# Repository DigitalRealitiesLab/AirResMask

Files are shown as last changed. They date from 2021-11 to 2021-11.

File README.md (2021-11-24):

# AirResMask

The repository contains building plans for the AirRes mask described in the following publication. Please cite this publication, if you build upon content of this repository:

Markus Tatzgern, Michael Domhardt, Martin Wolf, Michael Cenger, Gerlinde Emsenhuber, Radomir Dinic, Nathalie Gerner, and Arnulf Hartl. 2022. AirRes Mask: A Precise and Robust Virtual Reality Breathing Interface Utilizing Breathing Resistance as Output Modality. In CHI Conference on Human Factors in Computing Systems (CHI ’22), April 29-May 5, 2022, New Orleans, LA, USA. ACM, New York, NY, USA, https://doi.org/10.1145/3491102.3502090

The assembled mask:

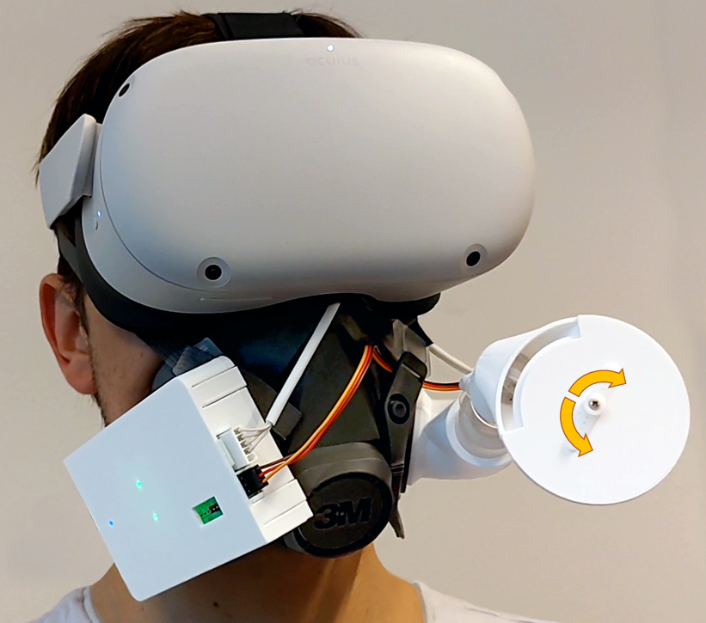
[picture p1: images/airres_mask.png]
Assembled Mask


Exploded view of mask showing components:

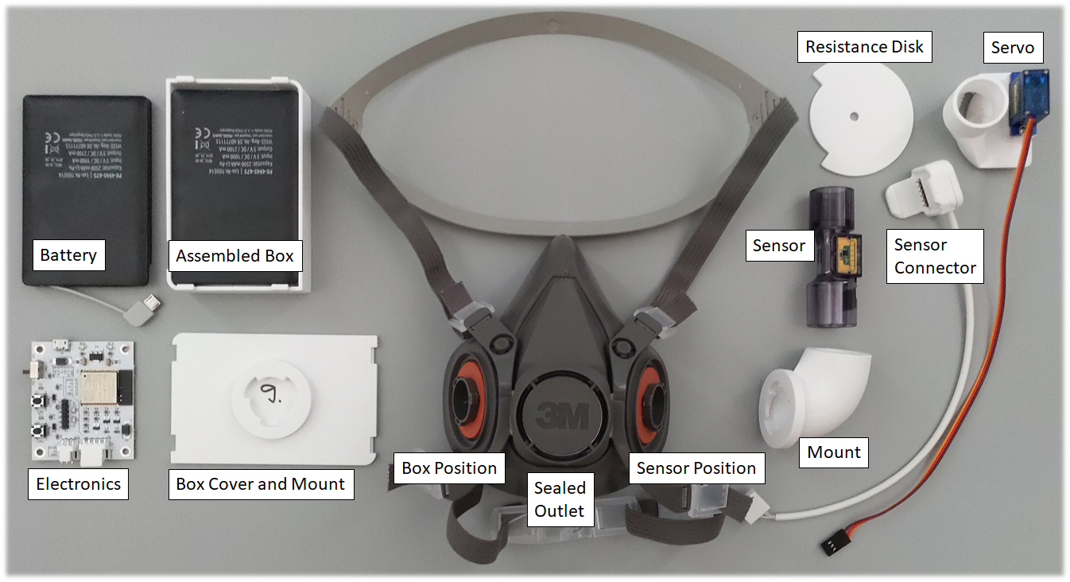
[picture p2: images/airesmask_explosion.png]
Exploded view of mask


Example applications realized with mask:

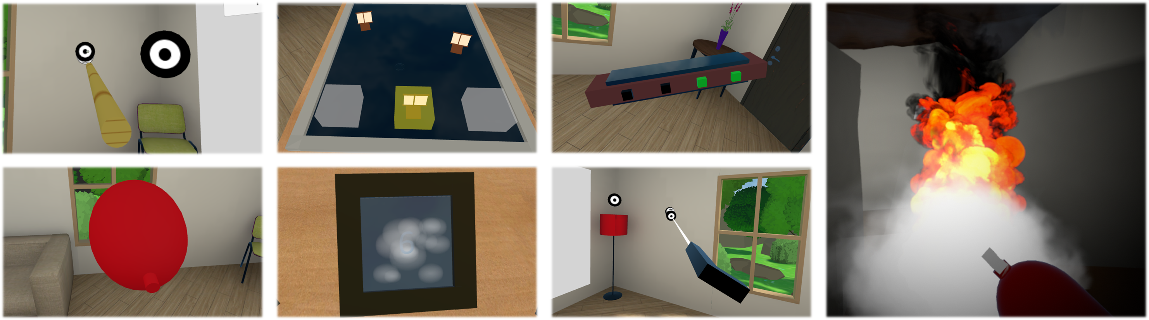
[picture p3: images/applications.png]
Example applications


This repository contains in the following folders:
- CAD: 3D models and printer files for custom parts of the mask
- Electronics: plans for custom electronics including a Bluetooth module
- Software: control software for the electronics and a Unity sample

Additional part list:
- Sensirion Mass Flow Meter [SFM3300](https://www.sensirion.com/en/flow-sensors/mass-flow-meters-for-high-precise-measurement-of-gases/proximal-flow-sensors-sfm3300-autoclavable-washable-or-single-use/) 
- [3M Respirator 6300](https://www.3m.com/3M/en_US/p/d/v000057396/)
- Servomotor SG90
- Power Bank with Micro USB connector

3rd party CAD files that could be interesting:
- [Servomotor SG90](https://grabcad.com/library/sg90-micro-servo-9g-tower-pro-1)
- Sensors: [SFM3300-D](https://www.sensirion.com/fileadmin/user_upload/customers/sensirion/Dokumente/5_Mass_Flow_Meters/Software/Sensirion_Mass_Flow_Meters_Software_SFM3300-D.step), [SFM3300-AW](https://www.sensirion.com/fileadmin/user_upload/customers/sensirion/Dokumente/5_Mass_Flow_Meters/Software/Sensirion_Mass_Flow_Meters_Software_SFM3300-D.step)

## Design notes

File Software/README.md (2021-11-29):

# Software

## Electronics

We use the [ESP32 library](https://github.com/espressif/arduino-esp32) of Espressif for programming the board.
In the folder ''Electronics'' you can find a file to program the circuit board, as well as the [ESP32Servo](https://github.com/madhephaestus/ESP32Servo) library. To upload the software to the board you need a SH-U09C2 or similar USB adapter.

You can find more ways to read and process SFML3300 sensor data [here](https://github.com/MyElectrons/sfm3300-arduino).

## UnitySample

This folder contains a simple Unity sample that demonstrates a version of the breathing engine where sensor values are received, transformed to forces to apply to the scene and breathing resistance can be set. To reduce the file size, we removed dependencies to the Oculus SDK. 

Additional 3rd party assets can be retrieved from the Unity Asset store:
[Arduino Bluetooth Plugin](https://assetstore.unity.com/packages/tools/input-management/arduino-bluetooth-plugin-98960)

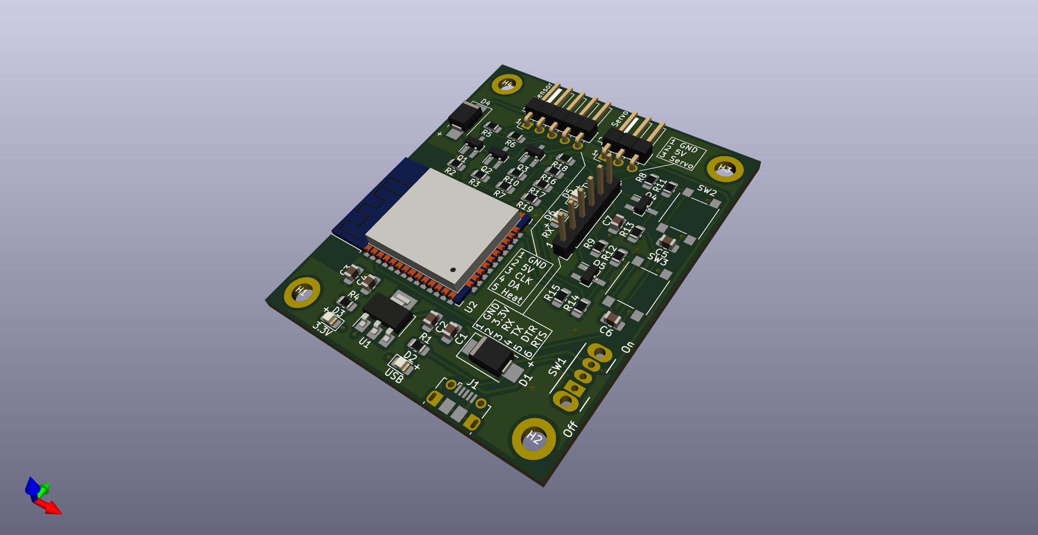
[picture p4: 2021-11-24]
Electronics/KiCAD/RespiratorIF_Board_3D_Front.jpg

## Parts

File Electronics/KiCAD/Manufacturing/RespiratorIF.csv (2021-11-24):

Comment | Designator | Footprint | LCSC
100nF | C1,C3 | Capacitor_SMD:C_0805_2012Metric_Pad1.18x1.45mm_HandSolder | C282732
47µF/10V | C2,C4 | Capacitor_SMD:C_1206_3216Metric_Pad1.33x1.80mm_HandSolder | C607993
1µF | C5,C6 | Capacitor_SMD:C_0805_2012Metric_Pad1.18x1.45mm_HandSolder | C46653
SK24 | D1,D4 | Diode_SMD:D_SMB_Handsoldering | C85272
LED green | D2,D3 | LED_SMD:LED_0805_2012Metric_Pad1.15x1.40mm_HandSolder | C84260
LED yellow | D5,D6 | LED_SMD:LED_0805_2012Metric_Pad1.15x1.40mm_HandSolder | C2296
MountingHole | H1,H2,H3,H4 | MountingHole:MountingHole_3.2mm_M3_ISO14580_Pad
Power | J1 | Connector_USB:USB_Micro-B_Molex-105017-0001 | C136000
Servo | J2 | Connector_PinHeader_2.54mm:PinHeader_1x03_P2.54mm_Horizontal | C92159
Sensor | J3 | Connector_PinHeader_2.54mm:PinHeader_1x05_P2.54mm_Horizontal | C492413
Program | J4 | Connector_PinHeader_2.54mm:PinHeader_1x06_P2.54mm_Vertical | C492405
BSS138 | Q1,Q2 | Package_TO_SOT_SMD:SOT-23_Handsoldering | C78284
AO3400A | Q3 | Package_TO_SOT_SMD:SOT-23_Handsoldering | C347475
S8050 | Q4,Q5 | Package_TO_SOT_SMD:SOT-23_Handsoldering | C444723
4.7kΩ | R1 | Resistor_SMD:R_0805_2012Metric_Pad1.20x1.40mm_HandSolder | C17673
100Ω | R11 | Resistor_SMD:R_0805_2012Metric_Pad1.20x1.40mm_HandSolder | C17408
470Ω | R14,R15 | Resistor_SMD:R_0805_2012Metric_Pad1.20x1.40mm_HandSolder | C21266
1kΩ | R4,R16,R17 | Resistor_SMD:R_0805_2012Metric_Pad1.20x1.40mm_HandSolder | C17513
10kΩ | R2,R3,R6,R7,R8,R9,R10,R12,R13 | Resistor_SMD:R_0805_2012Metric_Pad1.20x1.40mm_HandSolder | C17414
20kΩ | R5 | Resistor_SMD:R_0805_2012Metric_Pad1.20x1.40mm_HandSolder | C4328
Off/On | SW1 | Button_Switch_THT:SW_CuK_OS102011MA1QN1_SPDT_Angled | C393937
Reset | SW2 | Button_Switch_SMD:SW_Push_1P1T_NO_6x6mm_H9.5mm | C127509
Boot | SW3 | Button_Switch_SMD:SW_Push_1P1T_NO_6x6mm_H9.5mm | C127509
AMS1117-3.3 | U1 | Package_TO_SOT_SMD:SOT-223-3_TabPin2 | C6186
ESP32-WROOM-32 | U2 | RF_Module:ESP32-WROOM-32 | C82899

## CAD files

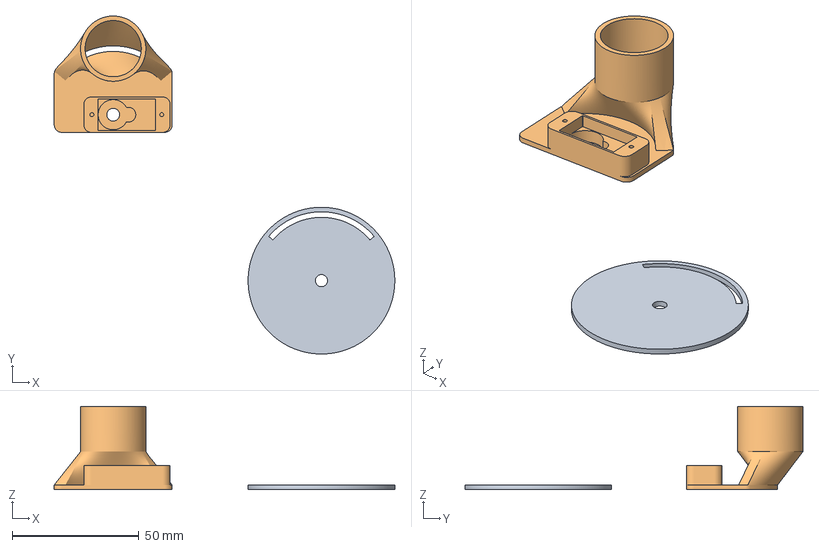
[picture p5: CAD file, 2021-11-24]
CAD/3D Print/AirValve_v3.3mf
134.6 x 133.5 x 32.8 mm
a3ac0385-cfff-4e33-9931-d9343202ccc4.stl
a6713ac3-0c4d-4182-9d5a-94dde946e7b5.stl

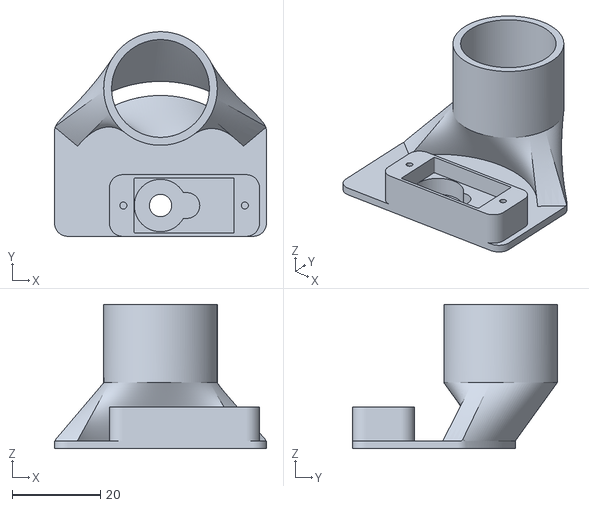
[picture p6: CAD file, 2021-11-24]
CAD/3D Print/gapWidth variable/Air Duct 3.1828.stl
48.2 x 46.5 x 32.8

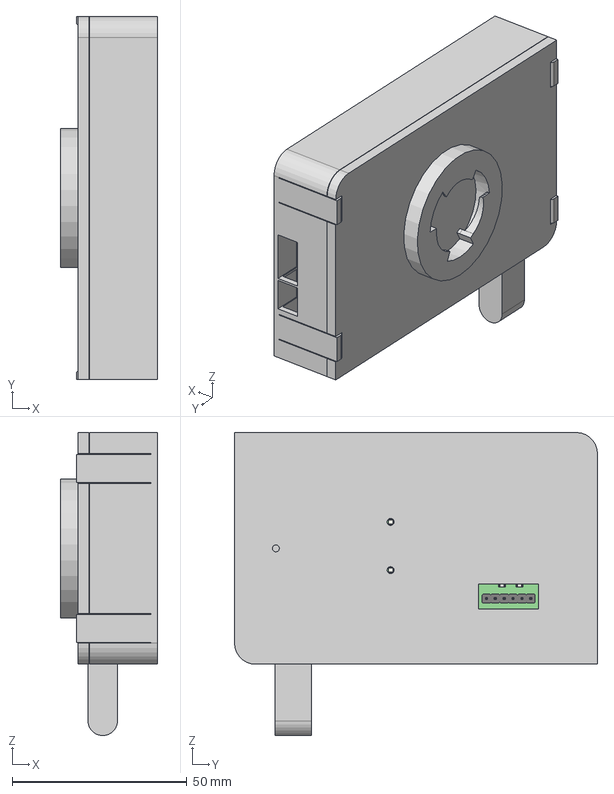
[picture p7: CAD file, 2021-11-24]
CAD/3M 6000 Series Electronic Box/3M 6000 Series Electronic Box v30.step
27.7 x 104.0 x 86.8 mm
Power Bank
Electronic Box

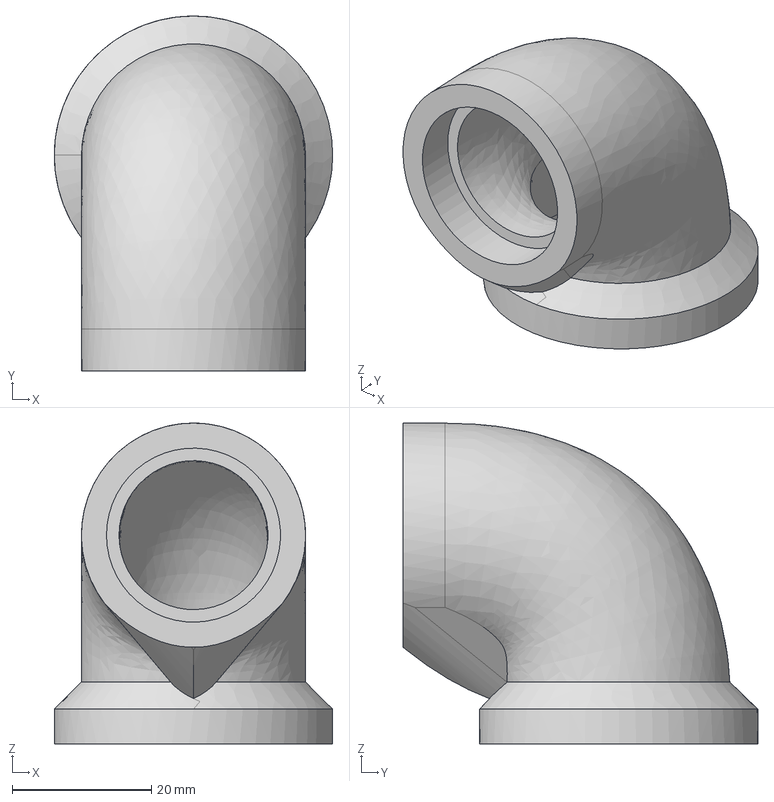
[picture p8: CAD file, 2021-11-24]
CAD/3M 6000 Series Sensor Adapter/3M 6000 Series Connector v3 v10.step
40.0 x 51.0 x 46.1 mm

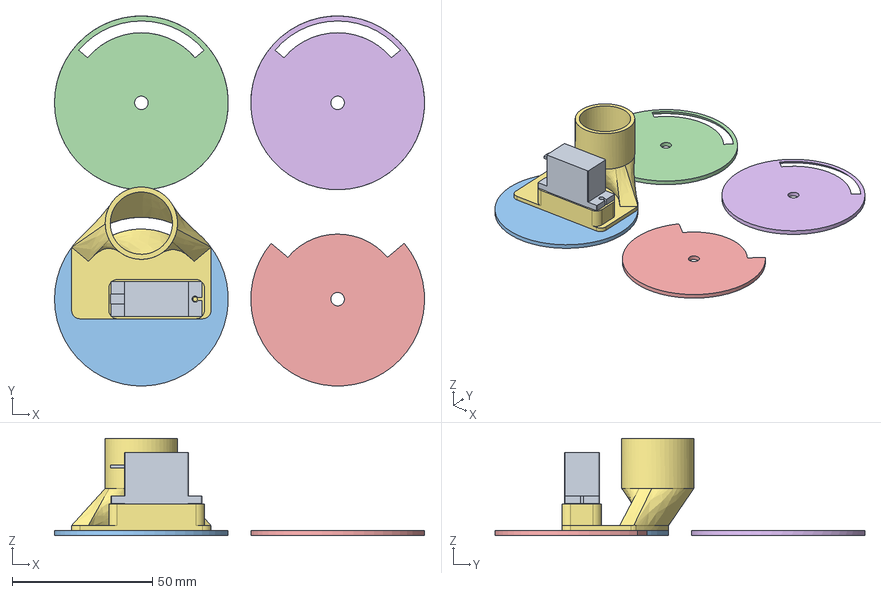
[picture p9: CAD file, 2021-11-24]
CAD/AirRestrictor/Air Valve 3rd Prototype v20.step
132.0 x 131.9 x 34.6 mm
servo
splined-drive
Air Restrictor
Air Duct

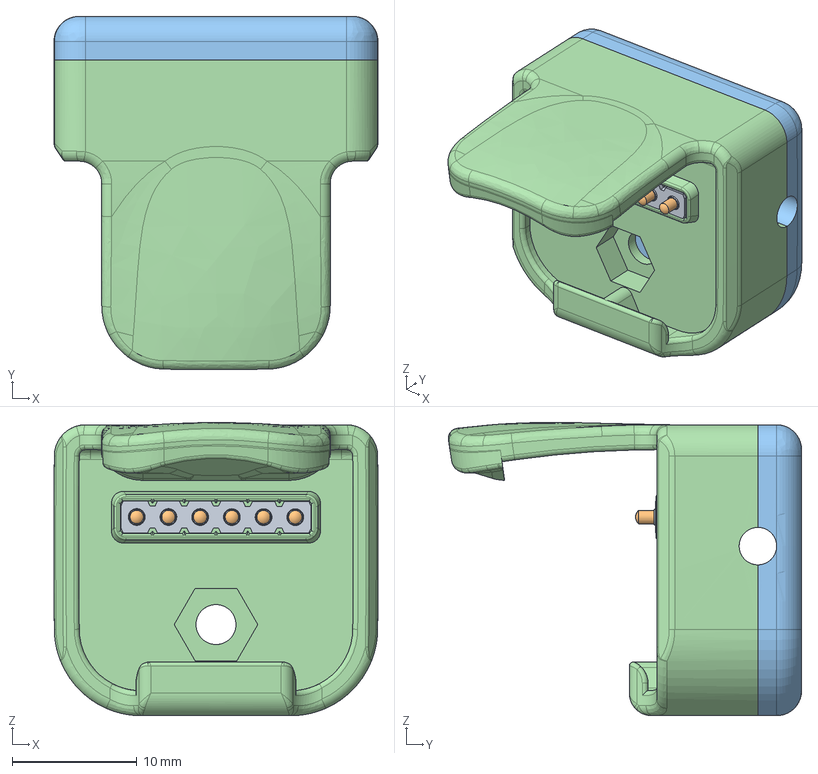
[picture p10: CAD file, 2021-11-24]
CAD/SensorPlug/SensorCap v2.step
25.9 x 28.3 x 23.5 mm

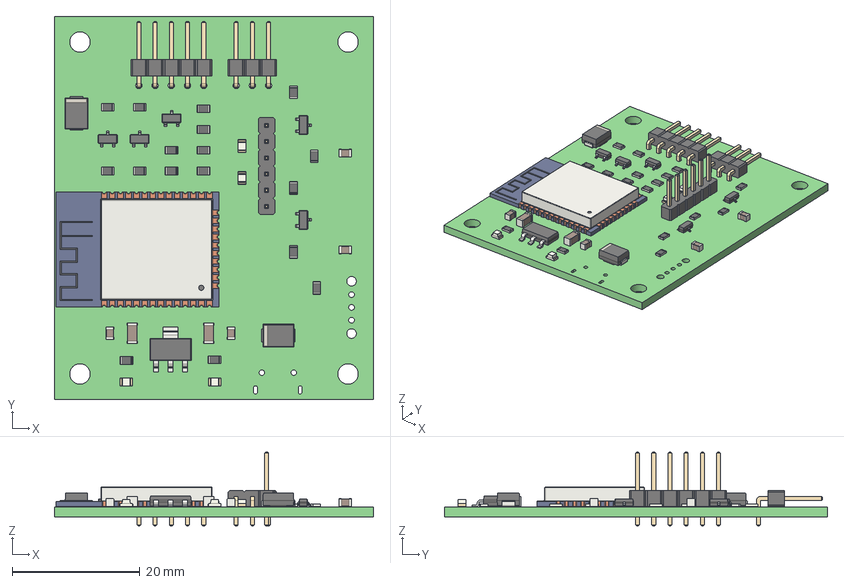
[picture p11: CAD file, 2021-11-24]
Electronics/Export4CAD/RespiratorIF v1.step
50.0 x 60.0 x 11.5 mm

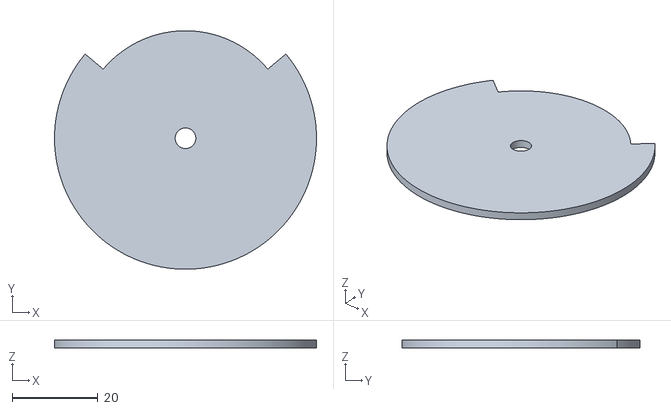
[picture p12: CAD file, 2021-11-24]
CAD/3D Print/gapWidth variable/Air Restrictor Clearance 3.6828.stl
61.0 x 55.5 x 1.80

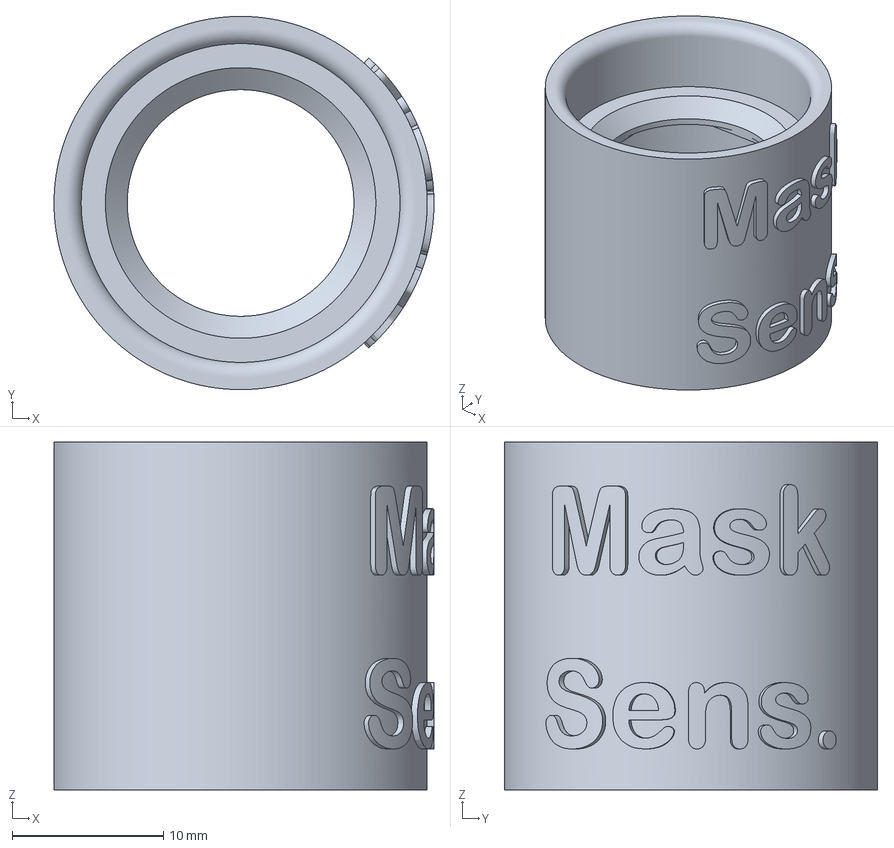
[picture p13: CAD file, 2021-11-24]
CAD/3D Print/Mask-Sensor-Adapter.3mf
25.2 x 24.7 x 23.0 mm

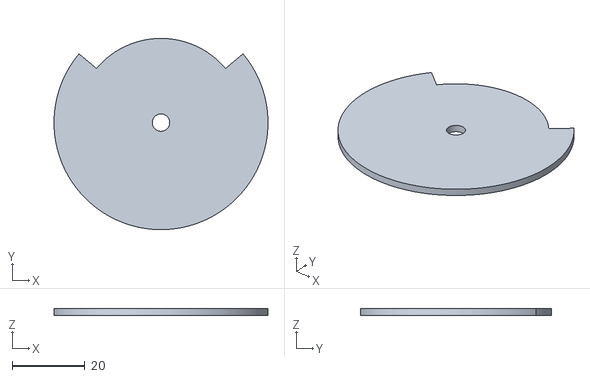
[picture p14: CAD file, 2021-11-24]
CAD/3D Print/gapWidth variable/Air Restrictor Clearance 2.6828.stl
59.0 x 52.7 x 1.80

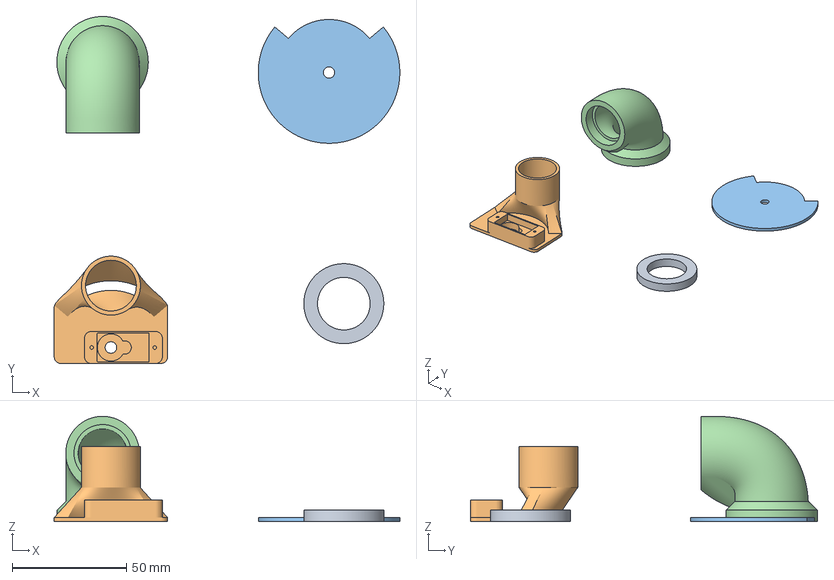
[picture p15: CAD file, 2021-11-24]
CAD/3D Print/MaskParts.3mf
151.3 x 151.9 x 46.1 mm
Ring.stl
Duct.stl
Disk.stl
Elbow.stl

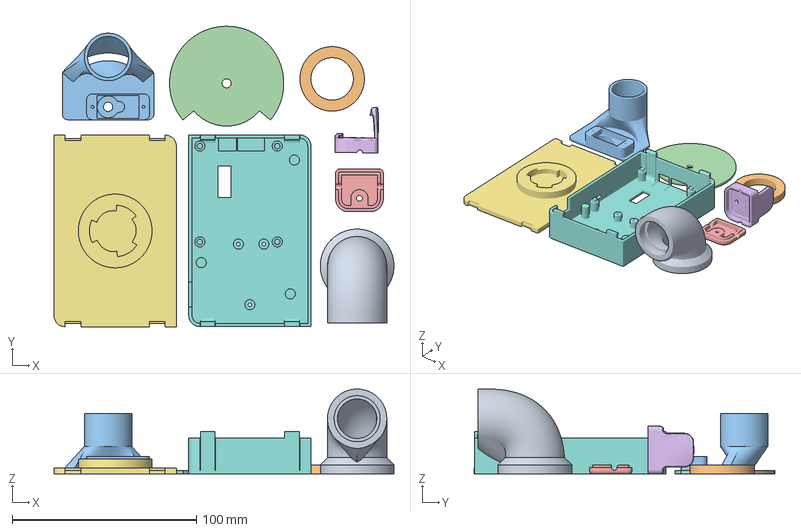
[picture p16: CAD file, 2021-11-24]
CAD/3D Print/AllParts4OneParticipant.3mf
184.5 x 163.1 x 46.1 mm
AirElbow.stl
AirBlockingRing.stl
AirDuct.stl
AirRestrictorDisc.stl
SensorClipLid.stl
SensorClip.stl
ElectronicBoxMedialHalf.stl
ElectronicBoxLateralHalf.stl

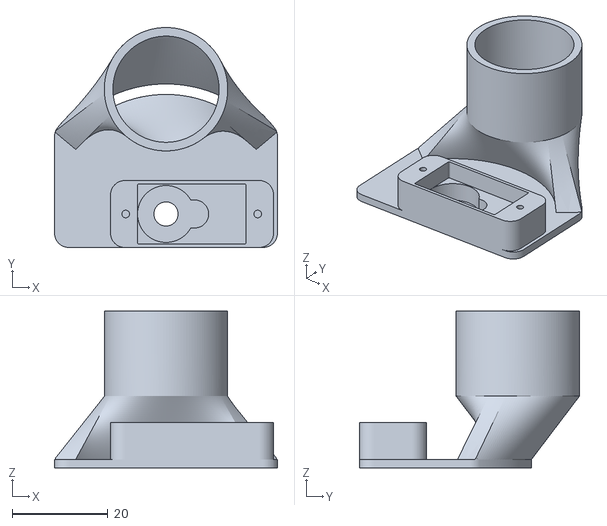
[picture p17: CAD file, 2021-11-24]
CAD/3D Print/gapWidth variable/Air Duct 2.1828.stl
46.6 x 46.0 x 32.8

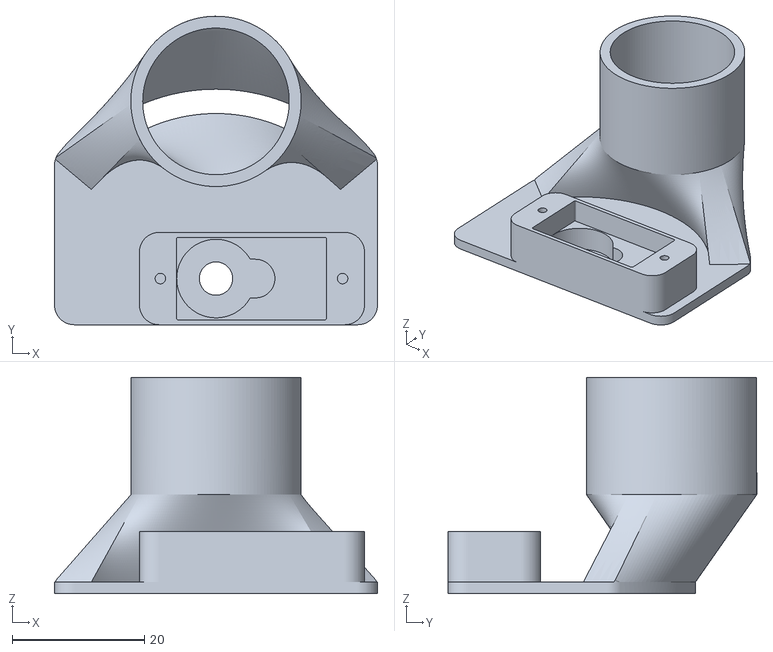
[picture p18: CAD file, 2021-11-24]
CAD/3D Print/gapWidth variable/Air Duct 3.6828.stl
48.9 x 46.7 x 32.8

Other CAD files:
CAD/3D Print/Plug Cover.stl
CAD/3D Print/gapWidth variable/Air Duct 2.6828.stl
CAD/3D Print/Plug Body.stl
CAD/3D Print/gapWidth variable/Air Restrictor Clearance 4.1828.stl
CAD/3D Print/Plug.3mf
CAD/3D Print/gapWidth variable/Air Duct 4.1828.stl
CAD/3D Print/gapWidth variable/Air Restrictor Clearance 2.1828.stl
CAD/3D Print/gapWidth variable/Air Restrictor Clearance 3.1828.stl
CAD/3M 6000 Series Electronic Box/3M 6000 Series Electronic Box v30.f3z
CAD/3M 6000 Series Sensor Adapter/3M 6000 Series Connector v3 v10.f3z
CAD/AirRestrictor/Air Valve 3rd Prototype v20.f3z
CAD/SensorPlug/SensorCap v2.f3d
Electronics/Export4CAD/RespiratorIF v1.f3d

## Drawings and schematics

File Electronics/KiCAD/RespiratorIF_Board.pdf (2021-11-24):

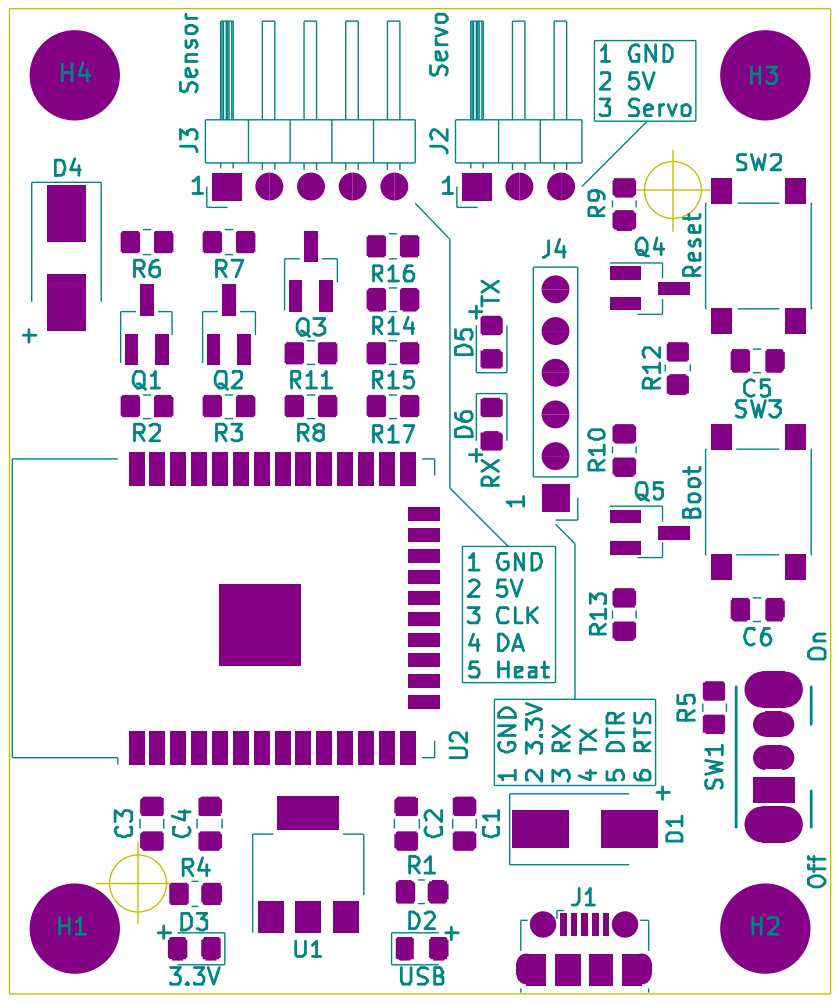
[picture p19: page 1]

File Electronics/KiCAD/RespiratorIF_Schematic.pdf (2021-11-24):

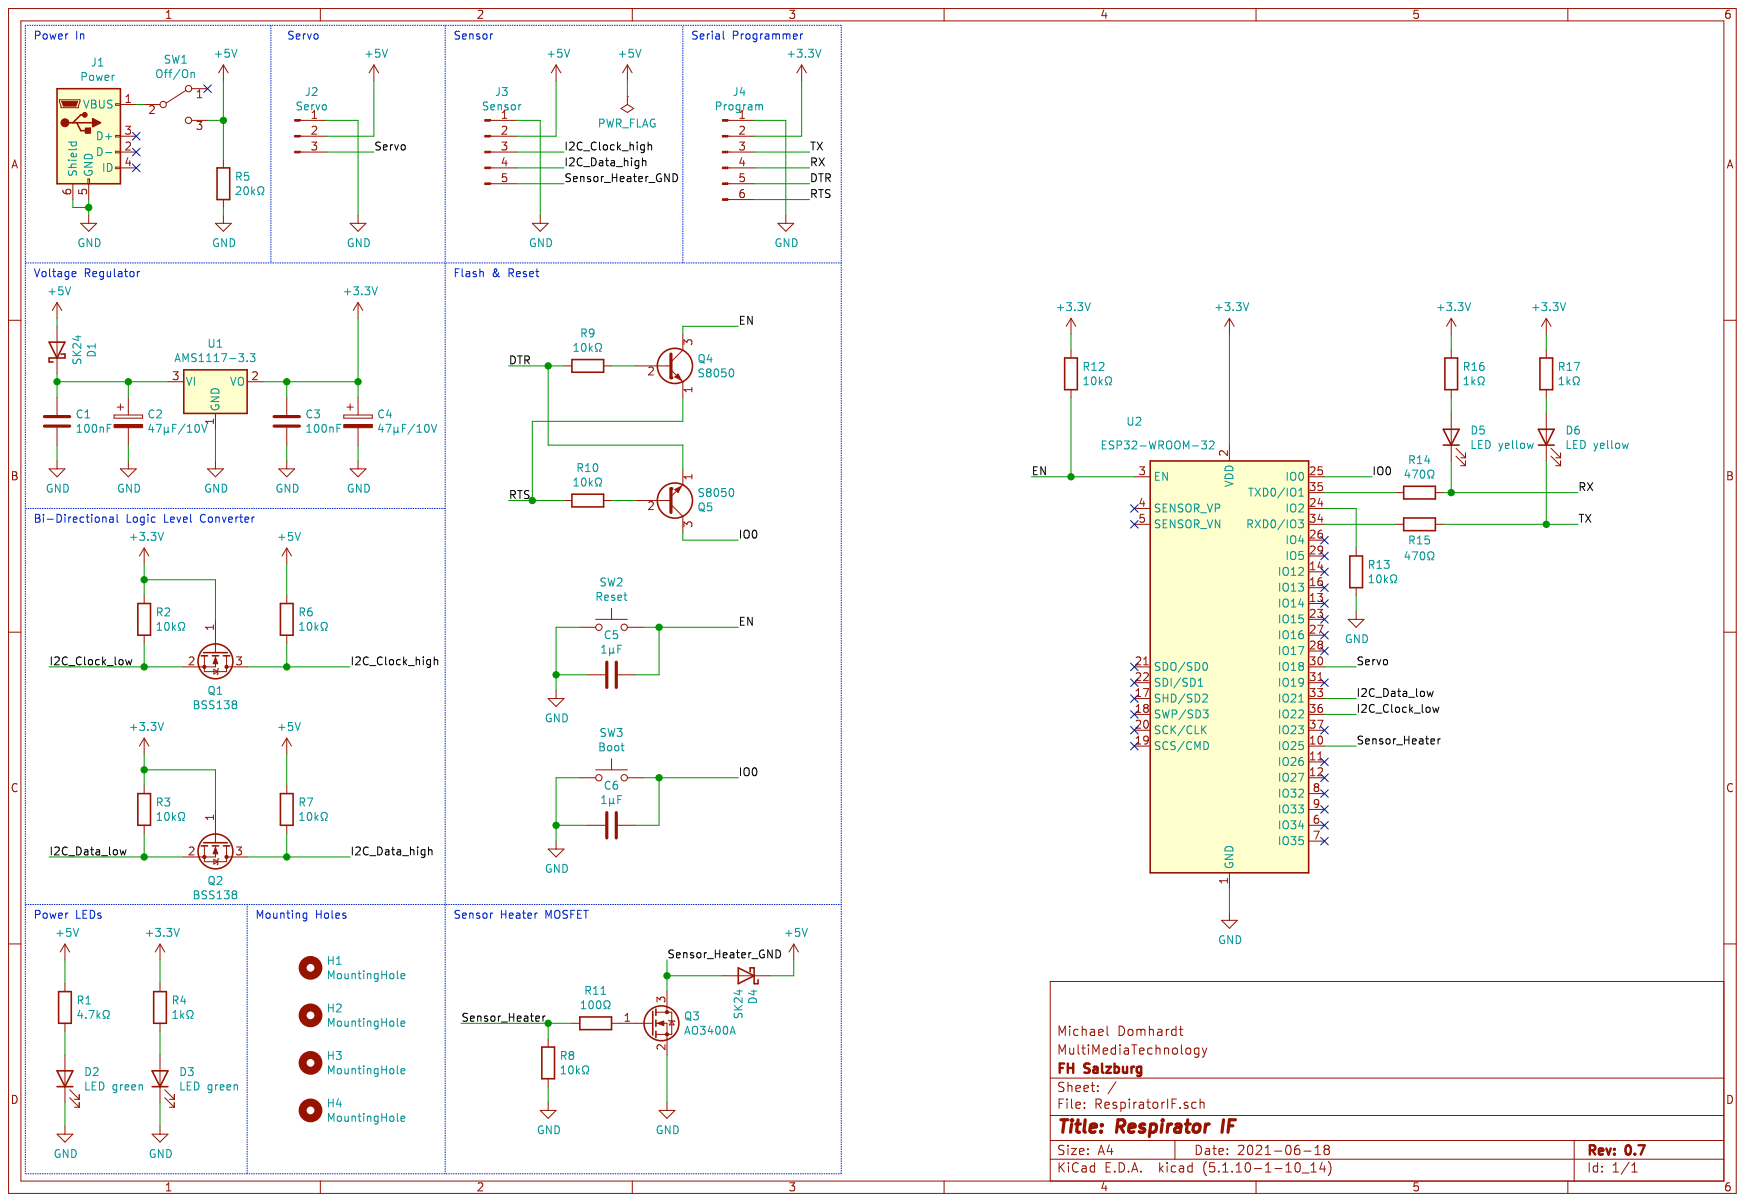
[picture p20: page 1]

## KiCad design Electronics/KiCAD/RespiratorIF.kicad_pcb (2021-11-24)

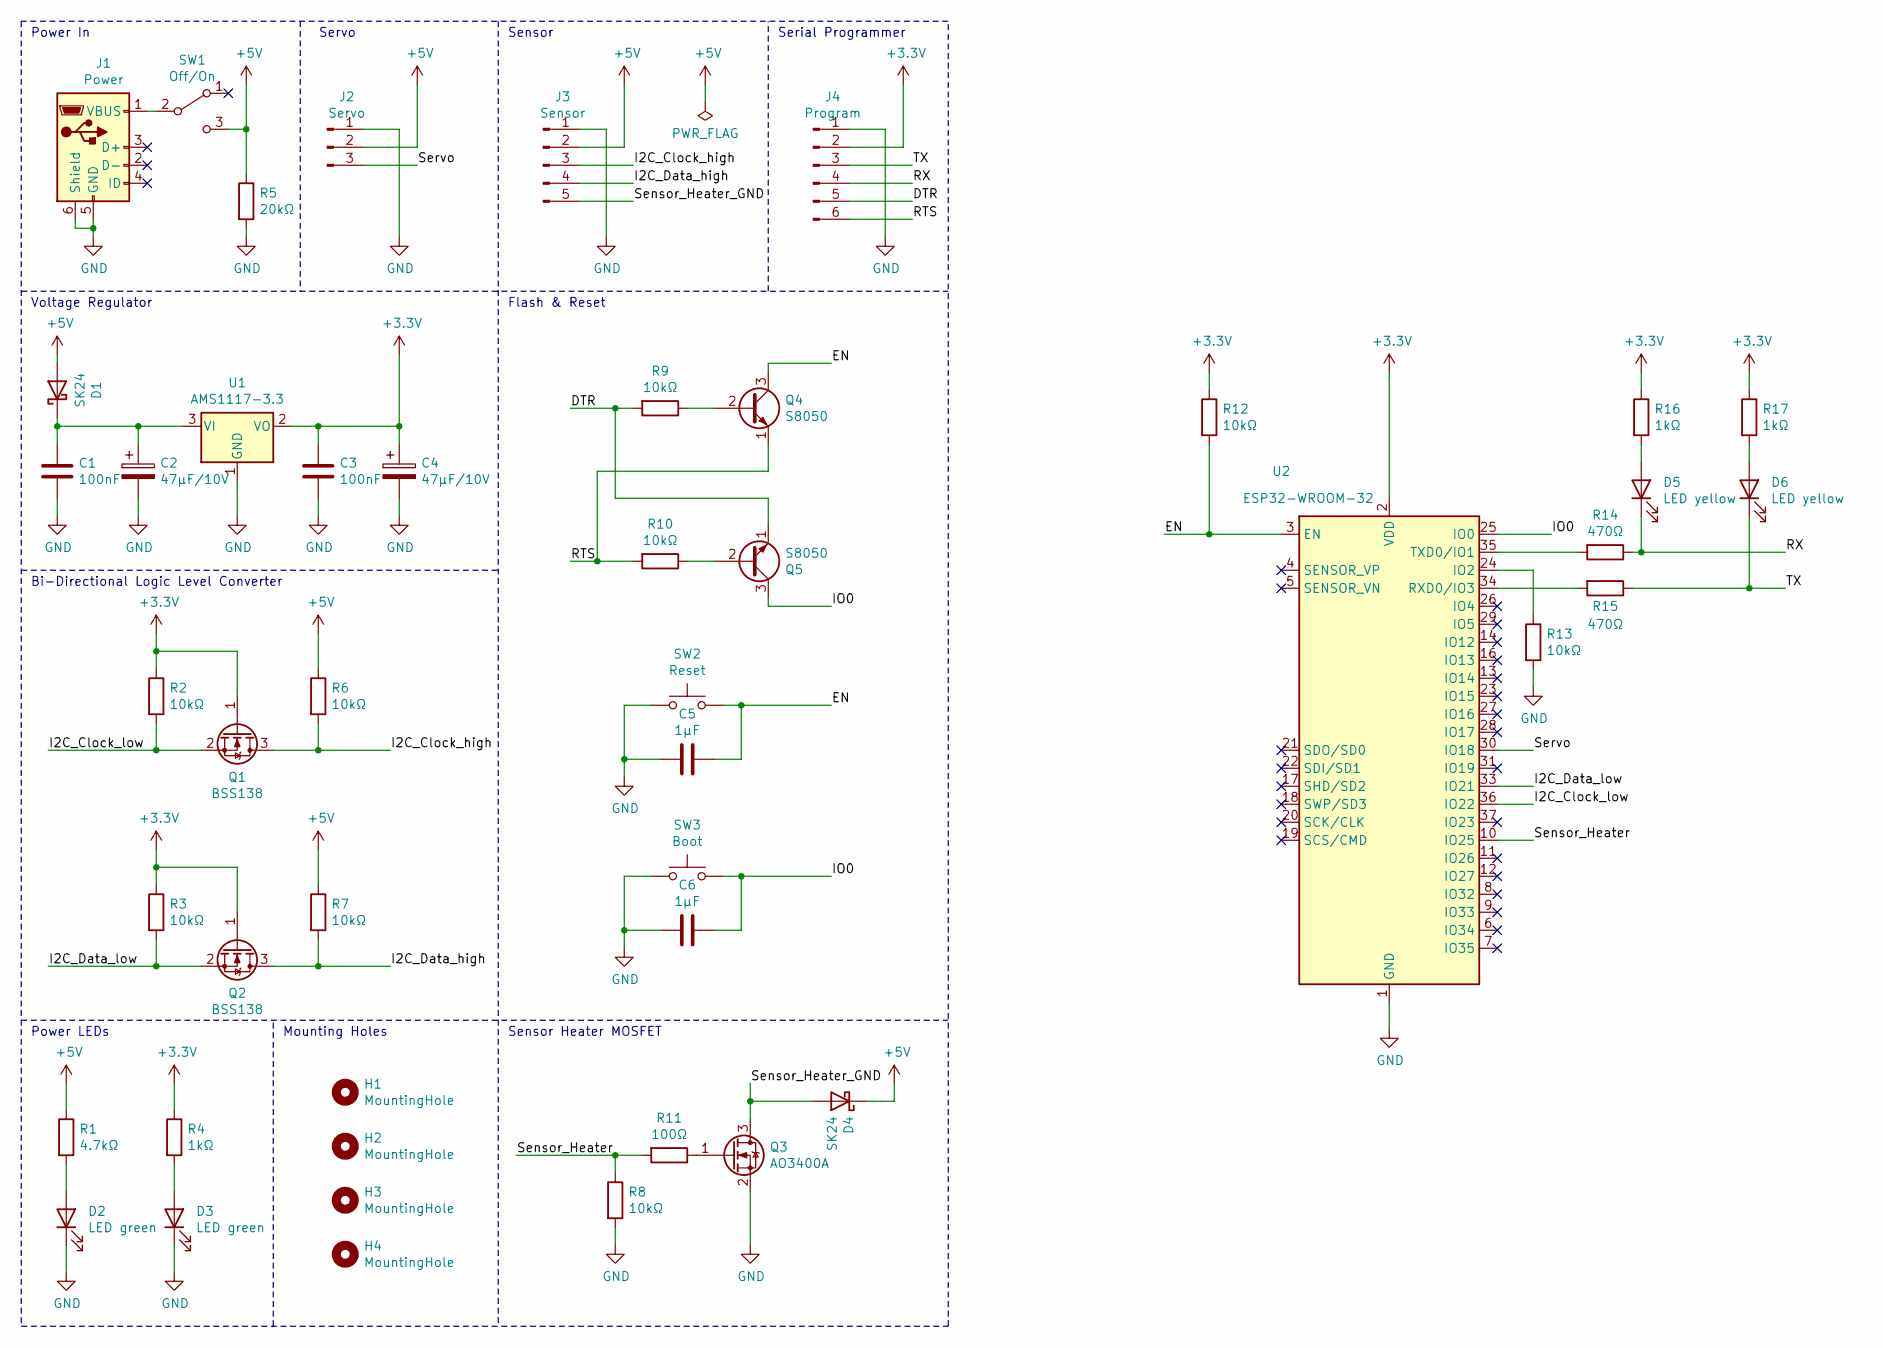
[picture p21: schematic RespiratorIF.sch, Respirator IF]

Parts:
C1, C3: 100nF; C_0805_2012Metric_Pad1.18x1.45mm_HandSolder; LCSC C282732
C2, C4: 47µF/10V; C_1206_3216Metric_Pad1.33x1.80mm_HandSolder; LCSC C76636
C5, C6: 1µF; C_0805_2012Metric_Pad1.18x1.45mm_HandSolder; LCSC C46653
D1, D4: SK24; D_SMB_Handsoldering; LCSC C85272
D2, D3: LED green; LED_0805_2012Metric_Pad1.15x1.40mm_HandSolder; LCSC C84260
D5, D6: LED yellow; LED_0805_2012Metric_Pad1.15x1.40mm_HandSolder; LCSC C2296
H1, H2, H3, H4: MountingHole; MountingHole_3.2mm_M3_ISO14580_Pad
J1: Power; USB_Micro-B_Molex-105017-0001; LCSC C136000
J2: Servo; PinHeader_1x03_P2.54mm_Horizontal; LCSC C92159
J3: Sensor; PinHeader_1x05_P2.54mm_Horizontal; LCSC C492413
J4: Program; PinHeader_1x06_P2.54mm_Vertical; LCSC C492405
Q1, Q2: BSS138; SOT-23_Handsoldering; LCSC C78284
Q3: AO3400A; SOT-23_Handsoldering; LCSC C347475
Q4, Q5: S8050; SOT-23_Handsoldering; LCSC C444723
R1: 4.7kΩ; R_0805_2012Metric_Pad1.20x1.40mm_HandSolder; LCSC C17673
R2, R3, R6, R7, R8, R9, R10, R12, R13: 10kΩ; R_0805_2012Metric_Pad1.20x1.40mm_HandSolder; LCSC C17414
R4, R16, R17: 1kΩ; R_0805_2012Metric_Pad1.20x1.40mm_HandSolder; LCSC C17513
R5: 20kΩ; R_0805_2012Metric_Pad1.20x1.40mm_HandSolder; LCSC C4328
R11: 100Ω; R_0805_2012Metric_Pad1.20x1.40mm_HandSolder; LCSC C17408
R14, R15: 470Ω; R_0805_2012Metric_Pad1.20x1.40mm_HandSolder; LCSC C21266
SW1: Off/On; SW_CuK_OS102011MA1QN1_SPDT_Angled; LCSC C393937
SW2: Reset; SW_Push_1P1T_NO_6x6mm_H9.5mm; LCSC C127509
SW3: Boot; SW_Push_1P1T_NO_6x6mm_H9.5mm; LCSC C127509
U1: AMS1117-3.3; SOT-223-3_TabPin2; LCSC C6186
U2: ESP32-WROOM-32; LCSC C82899

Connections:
+3V3: C3.1, C4.1, J4.2, Q1.1 (G), Q2.1 (G), R2.1, R3.1, R4.1, R12.1, R16.1, R17.1, U1.2 (VO), U2.2 (VDD)
+5V: D1.2 (A), D4.1 (K), J2.2, J3.2, R1.1, R5.1, R6.1, R7.1, SW1.3 (C)
/DTR: J4.5, Q5.1 (E), R9.2
/EN: C5.1, Q4.3 (C), R12.2, SW2.2, U2.3 (EN)
/I2C_Clock_high: J3.3, Q1.3 (D), R6.2
/I2C_Clock_low: Q1.2 (S), R2.2, U2.36 (IO22)
/I2C_Data_high: J3.4, Q2.3 (D), R7.2
/I2C_Data_low: Q2.2 (S), R3.2, U2.33 (IO21)
/IO0: C6.1, Q5.3 (C), SW3.2, U2.25 (IO0)
/RTS: J4.6, Q4.1 (E), R10.2
/RX: D5.1 (K), J4.4, R14.1
/Sensor_Heater: R8.1, R11.2, U2.10 (IO25)
/Sensor_Heater_GND: D4.2 (A), J3.5, Q3.3 (D)
/Servo: J2.3, U2.30 (IO18)
/TX: D6.1 (K), J4.3, R15.1
GND: C1.2, C2.2, C3.2, C4.2, C5.2, C6.2, D2.1 (K), D3.1 (K), J1.5 (GND), J1.6 (Shield), J2.1, J3.1, J4.1, Q3.2 (S), R5.2, R8.2, R13.2, SW2.1, SW3.1, U1.1 (GND), U2.1 (GND), U2.15 (GND), U2.38 (GND), U2.39 (GND)
unnamed: C1.1, C2.1, D1.1 (K), U1.3 (VI)
unnamed: D2.2 (A), R1.2
unnamed: D3.2 (A), R4.2
unnamed: D5.2 (A), R16.2
unnamed: D6.2 (A), R17.2
unnamed: J1.1 (VBUS), SW1.2 (B)
unnamed: Q3.1 (G), R11.1
unnamed: Q4.2 (B), R9.1
unnamed: Q5.2 (B), R10.1
unnamed: R13.1, U2.24 (IO2)
unnamed: R14.2, U2.35 (TXD0/IO1)
unnamed: R15.2, U2.34 (RXD0/IO3)

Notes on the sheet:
Servo
Power In
Voltage Regulator
Sensor
Bi-Directional Logic Level Converter
Serial Programmer
Power LEDs
Flash & Reset
Mounting Holes
Sensor Heater MOSFET

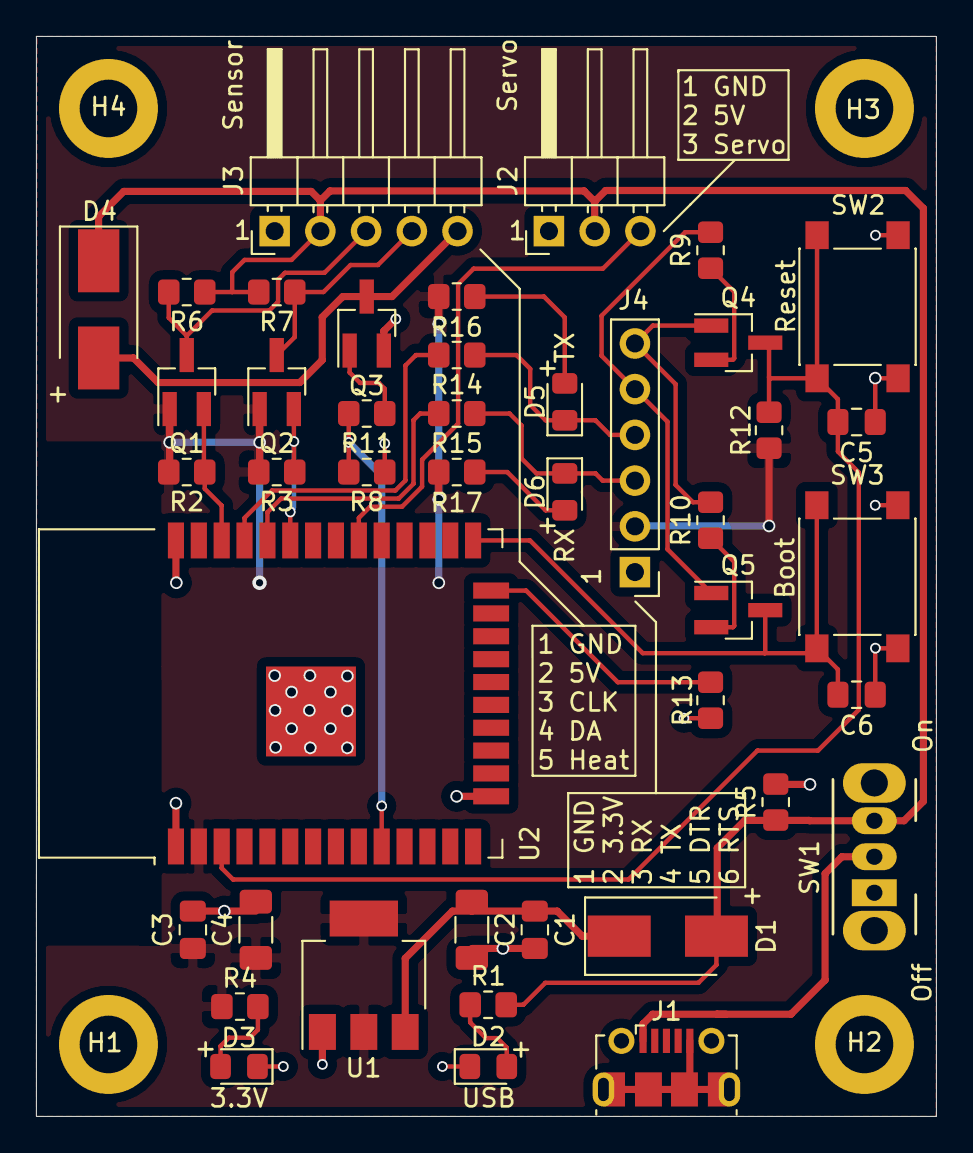
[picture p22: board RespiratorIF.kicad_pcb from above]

Board: 2 copper layers, 50.0 x 60.0 mm, 47 parts (0 on the bottom side), 28 nets.

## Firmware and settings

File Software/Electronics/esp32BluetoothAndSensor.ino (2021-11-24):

#include <ESP32Servo.h>
#include "BluetoothSerial.h"
#include <Wire.h>

#define POLYNOMIAL 0x31 // Martin Wolf: P(x)=x^8+x^5+x^4+1 = 100110001

BluetoothSerial BT;

Servo SM;
int maxAngle = 180;
int OutputPin = 18;

uint8_t CRC_prim (uint8_t x, uint8_t crc)
{
  crc ^= x;
  for (uint8_t bit = 8; bit > 0; --bit)
  {
    if (crc & 0x80)
    {
      crc = (crc << 1) ^ POLYNOMIAL;
    }
    else
    {
      crc = (crc << 1);
    }
  }
  return crc;
}

#define sfm3300i2c 0x40

const unsigned mms = 20; // Martin Wolf: Measurement interval in ms

void SFM_init()
{
  // Martin Wolf: Soft reset
  Wire.beginTransmission(sfm3300i2c);
  Wire.write(0x20);
  Wire.write(0x00);
  Wire.endTransmission();
  delay(100);

  // Martin Wolf: Start continuous measurement
  Wire.beginTransmission(sfm3300i2c);
  Wire.write(0x10);
  Wire.write(0x00);
  Wire.endTransmission();
  delay(100);
  
  // Martin Wolf: Discard the first chunk of data that is always 0xFF
  Wire.requestFrom(sfm3300i2c,3);
  while (Wire.available())
  {
    Wire.read();
  }
  delay(mms);
 
  // Martin Wolf: Discard the first value
  Wire.requestFrom(sfm3300i2c,3);
  while (Wire.available())
  {
    Wire.read();
  }
  delay(mms);
}

void setup()
{
  ESP32PWM::allocateTimer(0);
  ESP32PWM::allocateTimer(1);
  ESP32PWM::allocateTimer(2);
  ESP32PWM::allocateTimer(3);
  SM.setPeriodHertz(50);
  SM.attach(OutputPin, 500, 2500);
  Wire.begin();
  Serial.begin(115200);
  delay(500); // Martin Wolf: Let serial console settle
  SFM_init();
  BT.begin("InhaleVR");
}

bool crc_error;

void SFM_measure()
{
  if (3 == Wire.requestFrom(sfm3300i2c, 3))
  {
    uint8_t crc = 0;
    uint8_t a = Wire.read();
    crc = CRC_prim (a, crc);
    uint8_t  b = Wire.read();
    crc = CRC_prim (b, crc);
    uint8_t  c = Wire.read();
    
    if (crc_error = (crc != c))
    {
      return;
    }
    
    uint8_t values[2];
    values[0] = a;
    values[1] = b;
    if (BT.available() == 0 && BT.hasClient())
    {
      BT.write(values, 2); // Martin Wolf: Send sensor data as a two byte integer value
    }
  }
  else
  {
    while (Wire.available())
    {
      Wire.read();
    }
    SFM_init();
  }
}

void ChangeAirResistance(int value)
{
  if (value > maxAngle)
  {
    SM.write(maxAngle);
  }
  else if (value < 0)
  {
    SM.write(0);
  }
  else
  {
    SM.write(value);
  }
}

unsigned long ms_prev = millis();

void loop()
{
  unsigned long ms_curr = millis();
  // Martin Wolf: Soft interrupt every mms milliseconds
  if (ms_curr - ms_prev >= mms)
  {
    ms_prev = ms_curr;
    SFM_measure();

    if (!BT.hasClient())
    {
      ChangeAirResistance(0);
    }
  
    if (BT.available() > 0)
    {
      String msg = "";
      while (BT.available() > 0)
      {
        char c = BT.read();
        msg += c;
      }
      ChangeAirResistance(msg.toInt());
    }
  }
}

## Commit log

2021-11-24 Add files via upload
    Initial commit of building material for AirResMask
    [3M 6000 Series Connector v3 v10.f3z, 3M 6000 Series Connector v3 v10.step, 3M 6000 Series Electronic Box v30.f3z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]
2021-11-29 added Unity example that shows how sensor values are received, applied and resistance settings are sent back to the mask
